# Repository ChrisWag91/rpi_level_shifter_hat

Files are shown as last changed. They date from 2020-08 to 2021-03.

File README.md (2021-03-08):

 # RPI Level Shifter Hat
An open source Raspberry Pi Hat for bidirectional 3V3 to 5V level shifting

This device is intended to allow communication between a Raspberry Pi and a 5V microcontroller such as an Arduino.

*Example:*

**RASPBERRY Pi** <==3V3 Signal==> **RPI Level Shifter Hat** <==5V Signal==> **Arduino**

Make sure to check the steps given under *Usage & Setup*

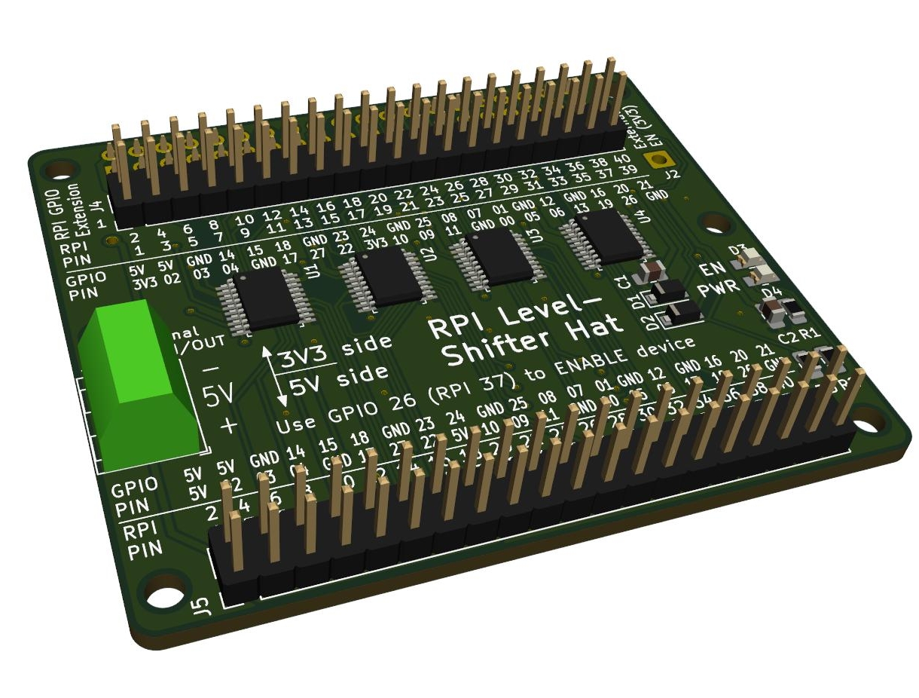
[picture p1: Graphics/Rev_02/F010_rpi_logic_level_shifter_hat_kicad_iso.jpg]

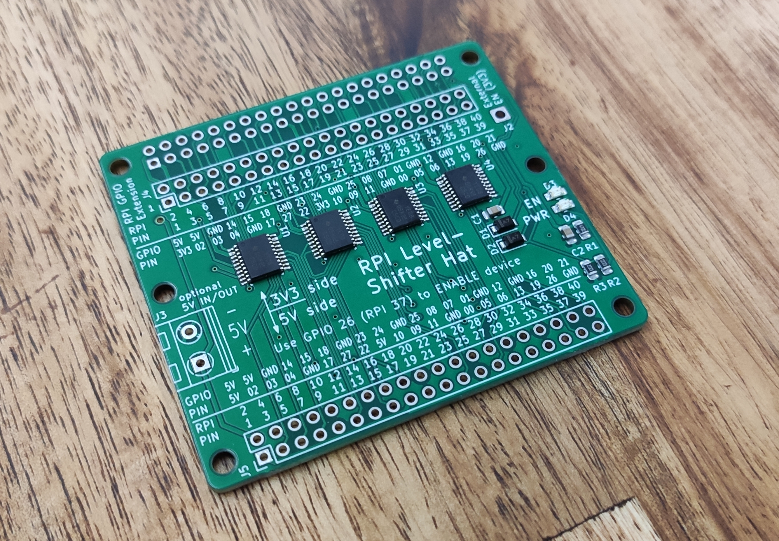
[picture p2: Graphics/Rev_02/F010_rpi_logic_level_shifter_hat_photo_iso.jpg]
 

## Features
- compatible with Raspberry Pi 2/3/4 (rev_00 and rev_02)
- compatible with Raspberry Pi Zero / Zero W (rev_02 only) 
- Bidirectional level shifting for all GPIOs
- Enable level shifter with RPI Pin 37 (GPIO Pin 26) 
- Optional 5V power in / out
- Optional Raspberry GPIO extension Header
- TXB0108 TI level shifter ICs ([Datasheet](https://www.ti.com/lit/ds/symlink/txb0108.pdf?ts=1597483061918&ref_url=https%253A%252F%252Fwww.google.com%252F))
- Enable indicator Led
- Power indicator Led
- Optional external enable (rev_02 only)

## Get PCB kits here:
https://www.tindie.com/products/chris_wag/rpi-level-shifter-hat/

https://www.ebay.de/itm/254895227518

## Mounting Hardware
- 1pcs  40 Pin Header Female (20x2 Pins)
- 1pcs  40 Pin Header Male (20x2 Pins) (optionally 0 or 2)
- 1pcs  screw Terminal P= 5mm (optional)
- 4pcs  M2.5 x 12mm Standoffs
- 4pcs  M2.5 x 5mm Screws

## Usage
1. Solder your Pin Headers as you need them. Make sure to mount the female header for the **Raspberry on the 3V3 side on the bottom of the PCB**. See the picture below. If you want to use 3V3 signals from the Raspberry directly also solder male headers to the footprint maked *RPI GPIO Extension*.
2. Optionally wire a 5V power supply in. This will be used to power both, the Raspberry Pi and the Levelshifter HAT. This should be done if you use lots of the 5V outputs with higher current draw
3. Configure your GPIOs as Input or Output as needed. See *Examples* for a python configuration sample.

Assemble as shown here:
(Make sure to connect the Raspberry to the 3V3 side)

 

## Setup
### Enable after boot and set GPIO drive strength
1. Install wiringpi on the Raspberry in order to set GPIO drive strength.
    ```console	
    sudo apt install wiringpi
    ```
    This allows us to increase the standard drive strength of the GPIOs from 8mA per IO to 12mA, 14mA or 16mA. Higher drive strength can be required to trigger the direction detection circuit on the level shifter ICs for more demanding 5V circuits.

2. Auto configure GPIO drive strength automatically after boot up.
    Therefore we add the command "gpio drive 0 6" to the autostart sequence
    ```console	
    sudo nano /etc/rc.local
    ```
    [Optional] Add the following line before "exit 0":
    ```console	
    gpio drive 0 6 &
    ```
    The value *6* in the end sets the output drive strength from the default 8mA to 14mA. This should help to reach the 5V logic level for more demanding output configurations.

3. Enable RPI Level Shifter Hat automatically after boot.
    This is done by pulling GPIO 26 high. 
    You can use *Wiringpi* or a python (see step 4) to do that.
     ```console	
    sudo nano /etc/rc.local
    ```
    Add the following line before "exit 0":
    ```console	
    gpio -g mode 26 out &
    gpio -g write 26 1 &
    ```

4. [Alternative to step 3]
    Copy the script "enable_rpi_logic_level_shifter.py" from the folder "Examples" to a local directory on your raspberry and add it to the autostart file as follows:

    ```console	
    sudo nano /etc/rc.local
    ```

    Add the following line before "exit 0":

    ```console	
    python /[insert local path to the enable script]/enable_rpi_logic_level_shifter.py &
    ```

After this setup your rc.local file should look similar to this (Content depends on your version of Raspberry OS):

```console	
   #!/bin/sh -e
    #
    # rc.local
    #
    # This script is executed at the end of each multiuser runlevel.
    # Make sure that the script will "exit 0" on success or any other
    # value on error.
    #
    # In order to enable or disable this script just change the execution
    # bits.
    #
    # By default this script does nothing.

    # Print the IP address
    _IP=$(hostname -I) || true
    if [ "$_IP" ]; then
    printf "My IP address is %s\n" "$_IP"
    fi

    gpio drive 0 6 &
    gpio -g mode 26 out &
    gpio -g write 26 1 &
    #python /home/pi/gpio_test_OUTPUT_with_Enable.py

    exit 0
```

## Versions
### rev_00
- initial release

### rev_02
- external enable pad added
- RPI Zero screw holes added
- correction & optimization of silk screen

*******************************************************************************************************************************

## Warning
This design is distributed in the hope that it will be useful, but WITHOUT ANY WARRANTY. Without even the implied warranty of MERCHANTABILITY or FITNESS FOR A PARTICULAR PURPOSE. See the GNU General Public License for more details.

## License
<a href="https://mirrors.creativecommons.org/presskit/buttons/88x31/png/by-nc.png
" target="_blank"></a>

License text: 
https://creativecommons.org/licenses/by-nc/3.0/

*******************************************************************************************************************************

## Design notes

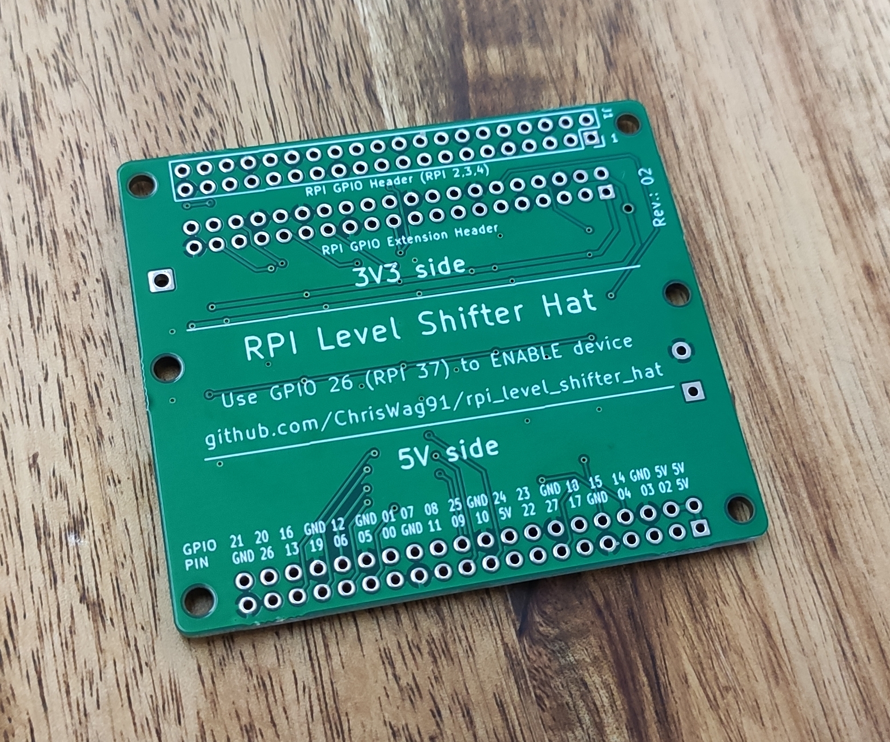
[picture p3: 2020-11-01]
Graphics/Rev_02/F010_rpi_logic_level_shifter_hat_photo_backside.jpg

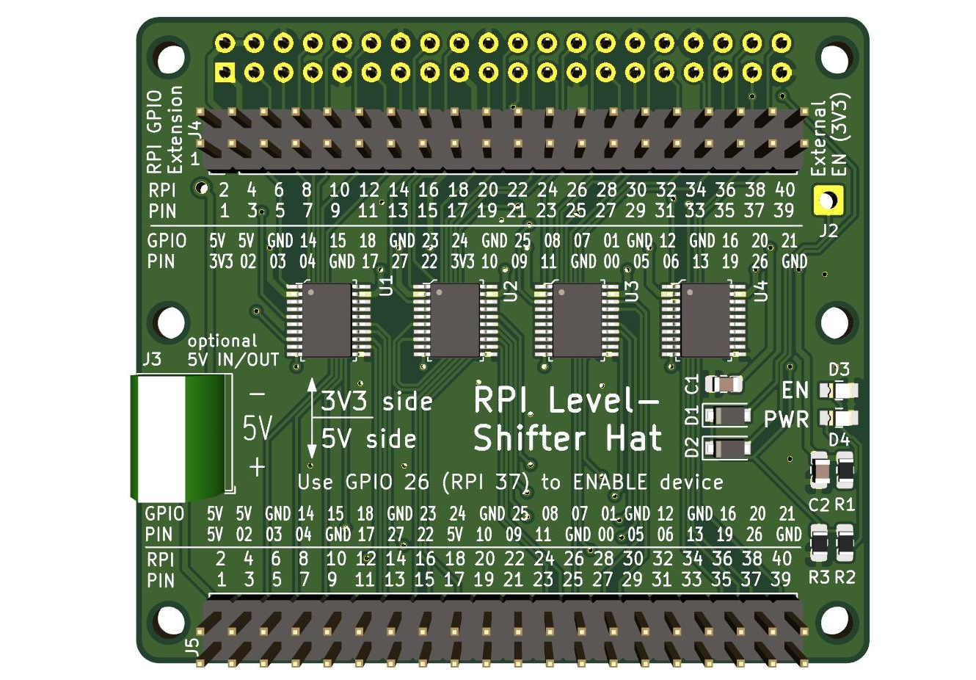
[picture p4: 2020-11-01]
Graphics/Rev_02/F010_rpi_logic_level_shifter_hat_kicad_top.jpg

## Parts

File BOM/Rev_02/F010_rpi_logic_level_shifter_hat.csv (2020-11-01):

Comment | Designator | Footprint | LCSC | LCSC
0.1uF | C1,C2 | Capacitor_SMD:C_0805_2012Metric_Pad1.15x1.40mm_HandSolder |  | C49678
D | D2,D1 | Diode_SMD:D_SOD-123F |  | C64898
LED_red | D4,D3 | digikey-footprints:0805 |  | C84256
Raspberry_Pi_2_3 | J1 | Connector_PinSocket_2.54mm:PinSocket_2x20_P2.54mm_Vertical
Ext_EN | J2 | Connector_Wire:SolderWire-0.75sqmm_1x01_D1.25mm_OD2.3mm
PWR_5V | J3 | TerminalBlock_RND:TerminalBlock_RND_205-00045_1x02_P5.00mm_Horizontal
rpi_extension_conn | J4 | Connector_PinHeader_2.54mm:PinHeader_2x20_P2.54mm_Vertical
rpi_extension_5V_conn | J5 | Connector_PinHeader_2.54mm:PinHeader_2x20_P2.54mm_Vertical
470R | R1 | Resistor_SMD:R_0805_2012Metric_Pad1.15x1.40mm_HandSolder |  | C17710
100R | R2 | Resistor_SMD:R_0805_2012Metric_Pad1.15x1.40mm_HandSolder |  | C17408
10K | R3 | Resistor_SMD:R_0805_2012Metric_Pad1.15x1.40mm_HandSolder |  | C17414
TXB0108PWR | U1,U2,U3,U4 | digikey-footprints:TSSOP-20_W4.4mm |  | C53406

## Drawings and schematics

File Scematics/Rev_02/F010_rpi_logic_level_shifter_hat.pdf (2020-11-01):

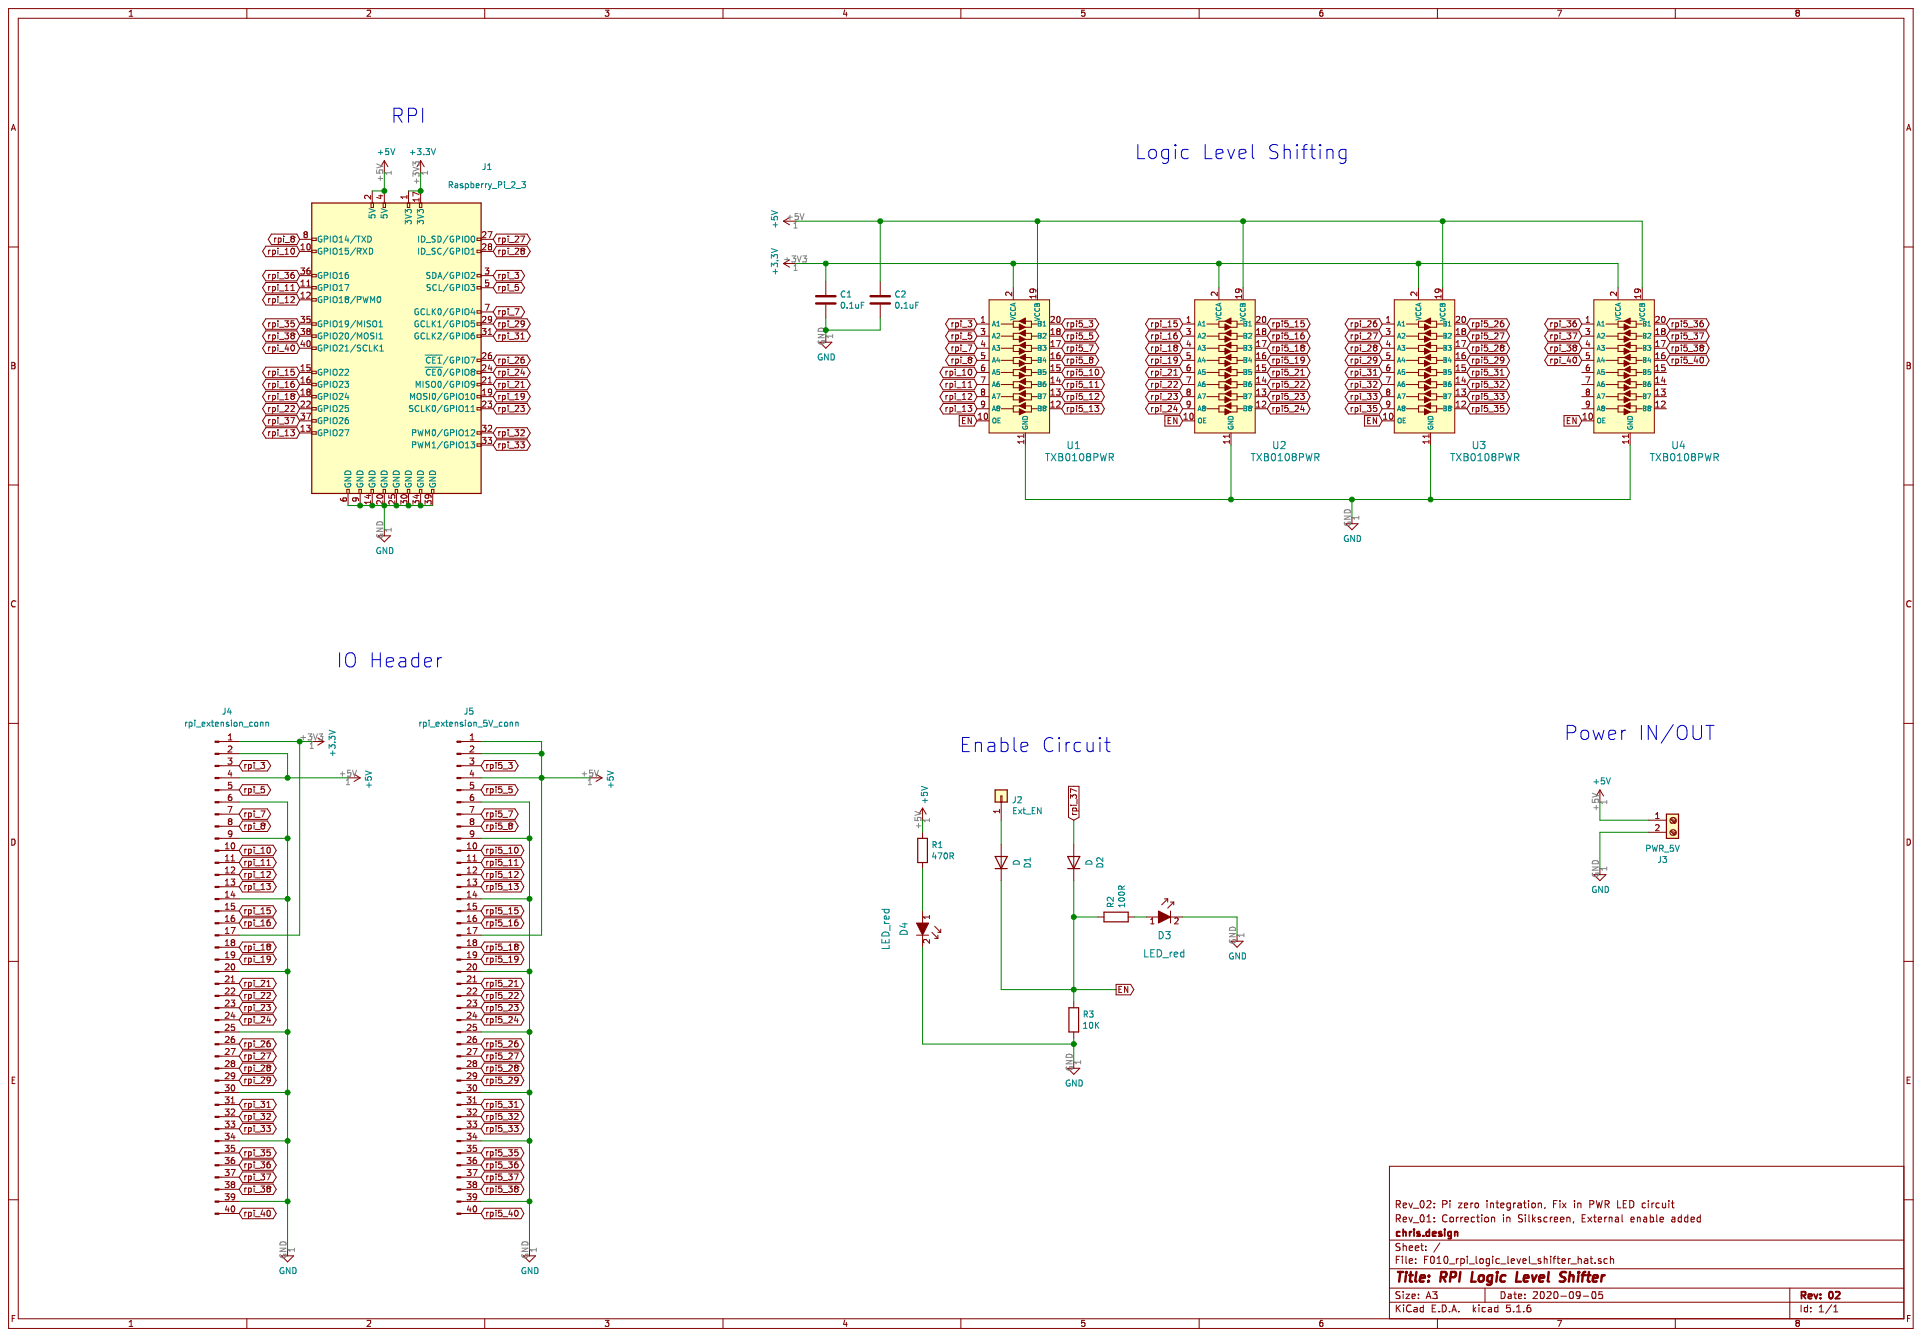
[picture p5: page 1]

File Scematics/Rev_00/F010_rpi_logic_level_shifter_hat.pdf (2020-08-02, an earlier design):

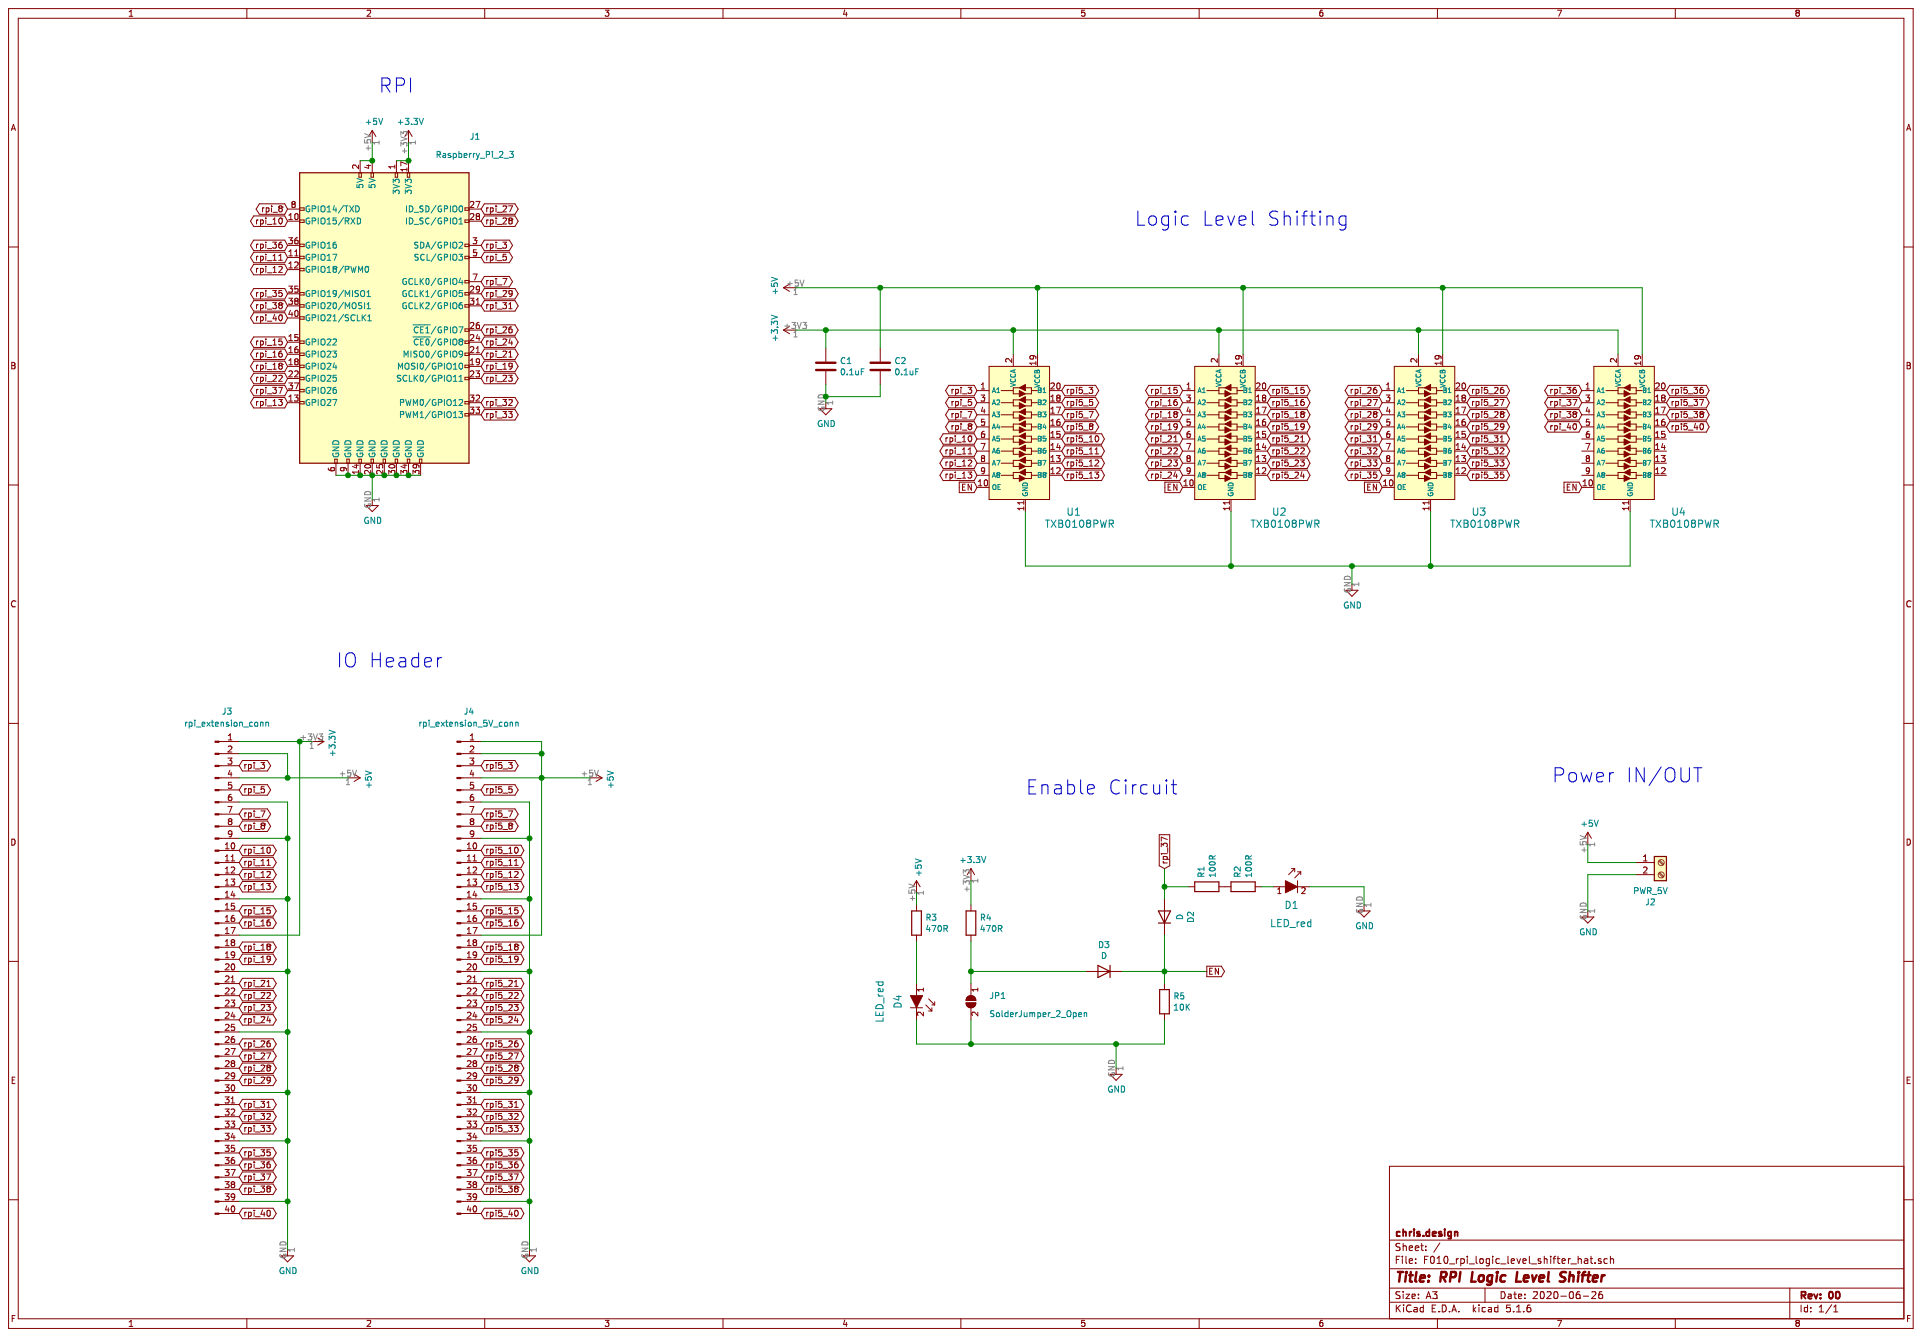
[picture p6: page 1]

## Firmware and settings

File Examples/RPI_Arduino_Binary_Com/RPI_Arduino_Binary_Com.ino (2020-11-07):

//# Demo binary communication between Raspberry Pi and Arduino
//# 4 bit Raspberry --> Arduino
//# 4 bit Arduino --> Raspberry

//# General Cycle
//# 1.    [Raspberry] Enable GPIO 26                              [Arduino] Start test signal
//# 2.    [Raspberry] Read IN bits                                [Arduino] Write OUT bits
//# 3.    [Raspberry] Write OUT bits                              [Arduino] Read IN bits
//# 4.    [Raspberry] Print IN bits                               [Arduino] Serial print IN bits

//# WIRING
//#
//# [RPI Level Shifter Hat]         [Arduino]
//# [GPIO; 5V Side]                 [Pin Nr]
//# 26             -->              4     ENABLE
//# 0              -->              14
//# 1              -->              15
//# 2              -->              32
//# 3              -->              34

//# 4              <--              36
//# 5              <--              12
//# 6              <--              10
//# 7              <--              17

#define BAUD (115200)
#define TESTDELAY 1000

//[RPI GPIO Nr] = [Arduino Pin]
int testPin0 = 14;
int testPin1 = 15;
int testPin2 = 32;
int testPin3 = 34;

int testPin4 = 36;
int testPin5 = 12;
int testPin6 = 10;
int testPin7 = 17;

int enablePin = 4; // Enable pin; start signal

// initial OUT values
bool outPin4 = 1;
bool outPin5 = 0;
bool outPin6 = 1;
bool outPin7 = 0;

int ledPin = 13; // select the pin for the LED

void setup()
{
  Serial.begin(BAUD);

  // Set IO Modes
  pinMode(testPin0, INPUT);
  pinMode(testPin1, INPUT);
  pinMode(testPin2, INPUT);
  pinMode(testPin3, INPUT);

  pinMode(enablePin, INPUT);

  pinMode(testPin4, OUTPUT);
  pinMode(testPin5, OUTPUT);
  pinMode(testPin6, OUTPUT);
  pinMode(testPin7, OUTPUT);

  pinMode(ledPin, OUTPUT);
  digitalWrite(ledPin, LOW);

  Serial.println("");
  Serial.println("Initialized");

  //STEP 1
  //Waiting for start signal
  Serial.println("");
  Serial.println("Waiting for start signal from RPI (GPIO 26 High)");

  while (not digitalRead(enablePin))
  {
    delay(TESTDELAY);
  }
  Serial.println("start communication...");
}

void loop()
{
  while (digitalRead(enablePin))
  {

    //STEP 2
    //Write OUT bits
    //Alternating values for test purposes
    Serial.println("");
    Serial.println("Writing OUT pins");
    Serial.println(outPin4);
    Serial.println(outPin5);
    Serial.println(outPin6);
    Serial.println(outPin7);

    digitalWrite(testPin4, outPin4);
    digitalWrite(testPin5, outPin5);
    digitalWrite(testPin6, outPin6);
    digitalWrite(testPin7, outPin7);

    digitalWrite(ledPin, outPin7); // just for visualisation

    //Invert OUT bits for next cycle
    outPin4 = not outPin4;
    outPin5 = not outPin5;
    outPin6 = not outPin6;
    outPin7 = not outPin7;

    //STEP 3 and 4
    //Read IN bits
    Serial.println("");
    Serial.println("Read IN pins");
    Serial.println(digitalRead(testPin0));
    Serial.println(digitalRead(testPin1));
    Serial.println(digitalRead(testPin2));
    Serial.println(digitalRead(testPin3));
    Serial.println("");
    Serial.println("---- Cycle complete ----");
    Serial.println("");

    delay(TESTDELAY);
  }
}

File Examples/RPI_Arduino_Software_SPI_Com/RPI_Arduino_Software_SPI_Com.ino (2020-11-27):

/*
  # Demo SPI communication between Raspberry Pi and Arduino

  # GENERAL FUNCTION
  # This is a simple example to demonstrate Software-SPI communication between a Raspberry (Master) with the RPI Level Shifter Hat and Arduino Mega (Slave)

  # WIRING
  # [RPI Level Shifter Hat]         [Arduino]
  # [GPIO; 5V Side]                 [Pin Nr]
  # 26             -->              4     ENABLE RPI Level Shifter Hat
  # 25             -->              21    CLK (Interrupt 2 Pin)
  # 1              <--              15    MISO
  # 2              -->              32    MOSI
  # 21             -->              3     CS (Interrupt 1 Pin)
*/

#define SCK_PIN 21 //Needs to be a Interrupt PIN https://www.arduino.cc/reference/en/language/functions/external-interrupts/attachinterrupt/
#define MISO_PIN 15
#define MOSI_PIN 32
#define SS_PIN 3 //Needs to be a Interrupt PIN

#define DEBUG LOW // Make sure to also set Debug True in the Python script if you set it HIGH here

volatile byte SPI_Byte = 0;
volatile byte SPI_Byte_tmp = 0;
volatile boolean Read_enable = LOW;
volatile int SPI_Counter = 8;
volatile boolean Write_enable = LOW;
volatile byte Write_data = 0xAA; //Massage to send to Raspberry. Fixed value for demo purposes

void setup()
{
  pinMode(SCK_PIN, INPUT);
  pinMode(MOSI_PIN, INPUT);
  pinMode(MISO_PIN, OUTPUT);
  pinMode(SS_PIN, INPUT);

  Serial.begin(115200);
  Serial.println("SPI slave mode");
  attachInterrupt(digitalPinToInterrupt(SS_PIN), SPI_slave_in, RISING); // RISING or FALLING
  attachInterrupt(digitalPinToInterrupt(SCK_PIN), SPI_transfer_bit, RISING);
}

void loop()
{

  if (SPI_Byte == 0x55)
  { //Check for Write Instruction
    Write_enable = HIGH;
    Read_enable = LOW;
    SPI_Byte = 0;
    if (DEBUG)
      Serial.println("Writing data");
  }
}

void SPI_slave_in()
{
  Read_enable = HIGH;
  Write_enable = LOW;
  //Serial.println("CS Active");
}

void SPI_transfer_bit()
{
  //
  // read SPI
  //
  if (Read_enable)
  {
    if (digitalRead(MOSI_PIN) == 1)
    {
      SPI_Byte_tmp = (SPI_Byte_tmp << 1) | 0x01; //Set "1"
      if (DEBUG)
        Serial.println("Read 1");
    }

    else
    {
      SPI_Byte_tmp = (SPI_Byte_tmp << 1) & 0xFE; //Set "0"
      if (DEBUG)
        Serial.println("Read 0");
    }

    SPI_Counter--;

    if (SPI_Counter <= 0)
    {
      Read_enable = LOW;
      SPI_Byte = SPI_Byte_tmp;
      Serial.println("Read data:");
      Serial.println(SPI_Byte, BIN);
      SPI_Byte_tmp = 0;
      SPI_Counter = 8;
    }
  }

  //
  // write SPI
  //
  if (Write_enable)
  {
    digitalWrite(MISO_PIN, bitRead(int(Write_data), SPI_Counter - 1));
    if (DEBUG)
      Serial.print("Write ");
    if (DEBUG)
      Serial.println(bitRead(int(Write_data), SPI_Counter - 1));

    SPI_Counter--;

    if (SPI_Counter <= 0)
    {
      Write_enable = LOW;
      Serial.println("Write Data:");
      Serial.println(Write_data, BIN);
      SPI_Counter = 8;
    }
  }
}

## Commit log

2020-08-02 upload of design files
    [F010_rpi_logic_level_shifter_hat-B_Cu.gbr, F010_rpi_logic_level_shifter_hat-B_Mask.gbr, F010_rpi_logic_level_shifter_hat-B_SilkS.gbr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]
2020-08-15 BOM Cleanup and Readme update
    [F010_rpi_logic_level_shifter_hat.csv]
2020-11-27 Software SPI Example
